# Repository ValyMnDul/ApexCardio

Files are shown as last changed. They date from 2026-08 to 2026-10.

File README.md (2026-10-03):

# ApexCardio

A portable cardiac and respiratory monitoring system built with an ESP32, ADS1292R and a Flutter mobile application.

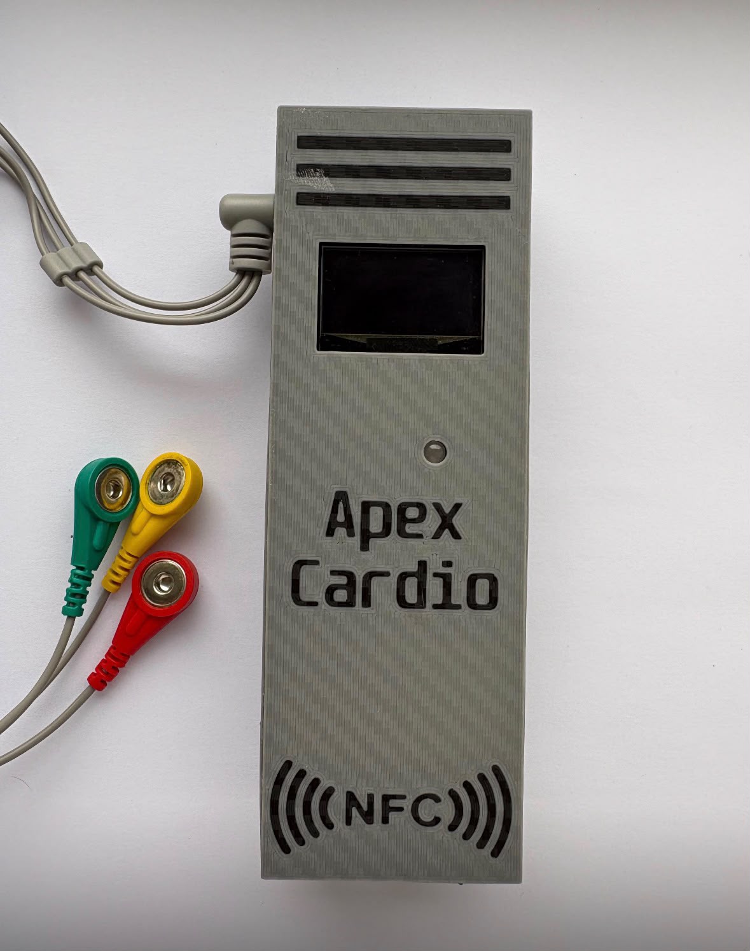
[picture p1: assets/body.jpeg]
Body


## Mobile App Screenshots

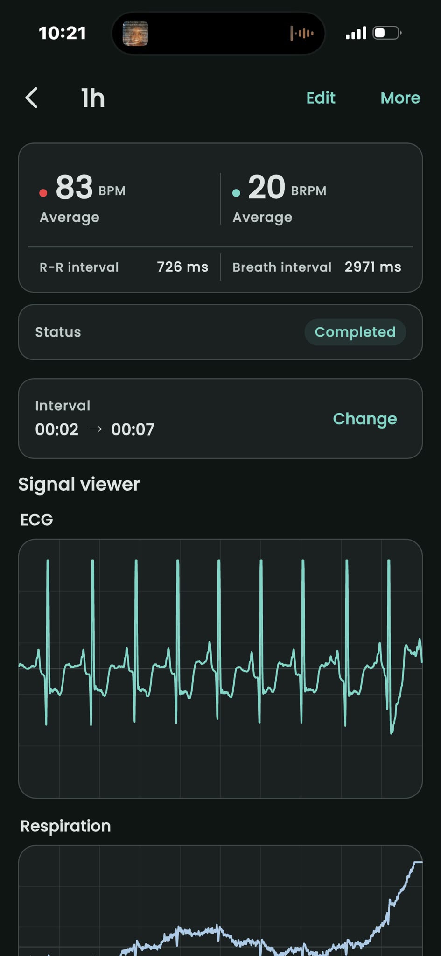
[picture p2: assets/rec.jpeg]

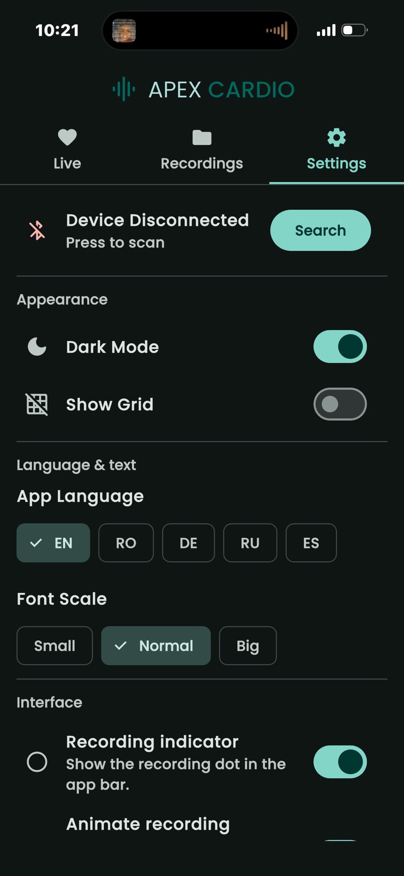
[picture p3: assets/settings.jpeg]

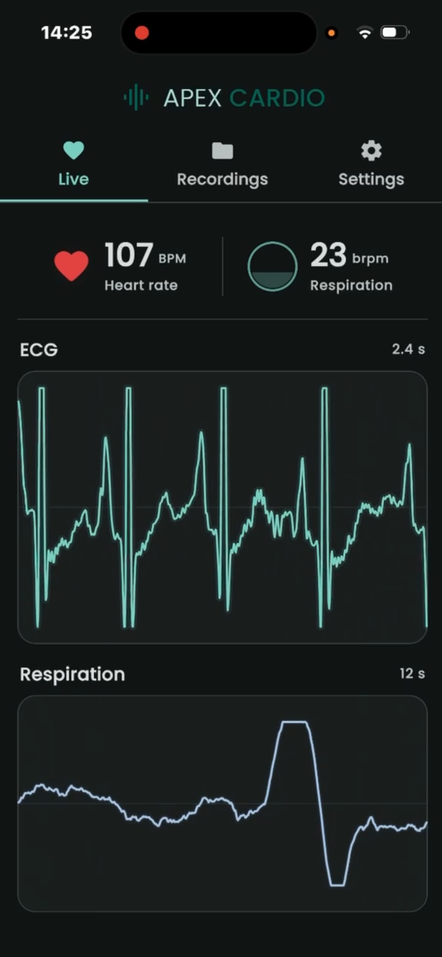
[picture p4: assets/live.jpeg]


## Features

- Real-time ECG monitoring
- Real-time respiratory monitoring
- Heart rate and respiratory rate
- Bluetooth Low Energy communication
- Live data visualization
- Recording and local storage with SQLite
- PDF and CSV export
- Automatic Bluetooth reconnection
- OLED display on the device

## Mobile App

The Flutter application is used to connect to the device, display ECG and respiratory data in real time, record measurements and manage saved recordings.

The app can work offline and stores recordings locally using SQLite.

## Hardware

The device uses:

- ESP32
- ADS1292R
- OLED display
- Rechargeable 18650 batteries
- ECG electrodes
- RGB status LED

The ADS1292R allows the device to acquire ECG and impedance-based respiratory signals using the same electrodes.

## Development

Most of my documented development time was spent working on the Flutter application, including the interface, Bluetooth communication, data buffering, live graphs, recording system, SQLite storage and export features.

I was not able to properly track the hardware development time because I did not have a good enough webcam to document the work, and recording the hardware work was difficult.

## Project Goal

The goal of ApexCardio is to create a compact and portable monitoring device that can acquire, process and display physiological signals without requiring a computer or external power source.

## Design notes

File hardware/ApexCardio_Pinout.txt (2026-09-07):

ApexCardio Hardware Pinout
Current ESP32 firmware pinout

ESP32 to ADS1292R / CJMCU-1292
GPIO18  -> SCK
GPIO19  -> MISO
GPIO23  -> MOSI
GPIO5   -> CS
GPIO22  -> DRDY
GPIO4   -> START
GPIO33  -> RESET / PWDN
5V/VIN  -> VDD / 5V
GND     -> GND

ADS1292R SPI settings
Clock: 100 kHz
Bit order: MSB first
SPI mode: MODE1

ESP32 to OLED SH1106 128x64
GPIO21  -> SDA
GPIO25  -> SCL
GND     -> GND
VCC     -> OLED supply

OLED interface: I2C
OLED bus clock used by firmware: 800 kHz

Current status LED
GPIO2   -> Status LED

Firmware behavior:
GPIO2 HIGH -> BLE connected
GPIO2 LOW  -> BLE disconnected

RGB LED extension
LED type: 5 mm RGB, common anode

Common anode -> ESP32 3.3V
Red cathode   -> 220-330 ohm resistor -> GPIO26
Green cathode -> 220-330 ohm resistor -> GPIO27
Blue cathode  -> 220-330 ohm resistor -> GPIO32

For a common-anode RGB LED:
GPIO LOW  -> color ON
GPIO HIGH -> color OFF

Note: GPIO26, GPIO27 and GPIO32 are free in the current main.cpp. The current firmware does not yet control the RGB LED on these pins.

Power system
Battery pack: 2 x 18650 Li-ion cells in parallel (1S2P)

Battery pack + -> TP4056 B+
Battery pack - -> TP4056 B-

TP4056 OUT+ -> MT3608 input +
TP4056 OUT- -> MT3608 input -

MT3608 output adjusted to 5.0 V

MT3608 output + -> ESP32 5V/VIN
MT3608 output - -> ESP32 GND

ESP32 5V/VIN -> CJMCU-1292 VDD / 5V
ESP32 GND -> CJMCU-1292 GND
ESP32 GND -> OLED GND

All system grounds must be common.

ECG electrode placement used during testing
Red electrode    -> below the right clavicle
Yellow electrode -> below the left clavicle
Third electrode  -> lower-right torso / RLD reference

The electrode cable connects to the CJMCU-1292 electrode input connector.

GPIO summary
GPIO2   -> Current status LED
GPIO4   -> ADS1292R START
GPIO5   -> ADS1292R CS
GPIO18  -> ADS1292R SCK
GPIO19  -> ADS1292R MISO
GPIO21  -> OLED SDA
GPIO22  -> ADS1292R DRDY
GPIO23  -> ADS1292R MOSI
GPIO25  -> OLED SCL
GPIO33  -> ADS1292R RESET / PWDN

Reserved for RGB extension:
GPIO26  -> RGB Red
GPIO27  -> RGB Green
GPIO32  -> RGB Blue

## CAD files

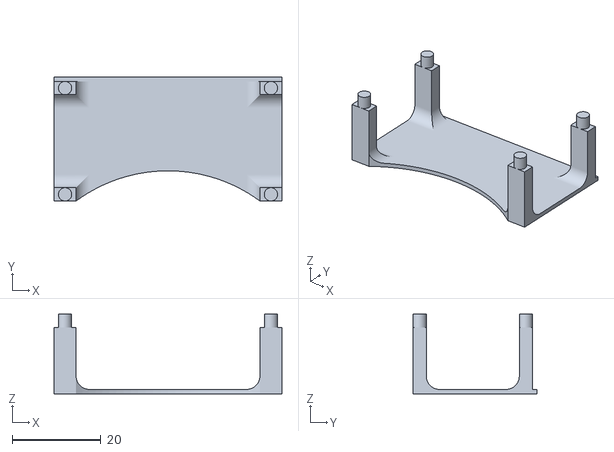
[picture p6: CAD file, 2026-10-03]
hardware/CAD/heartbot_screen_hold.stl
51.5 x 28.0 x 18.0

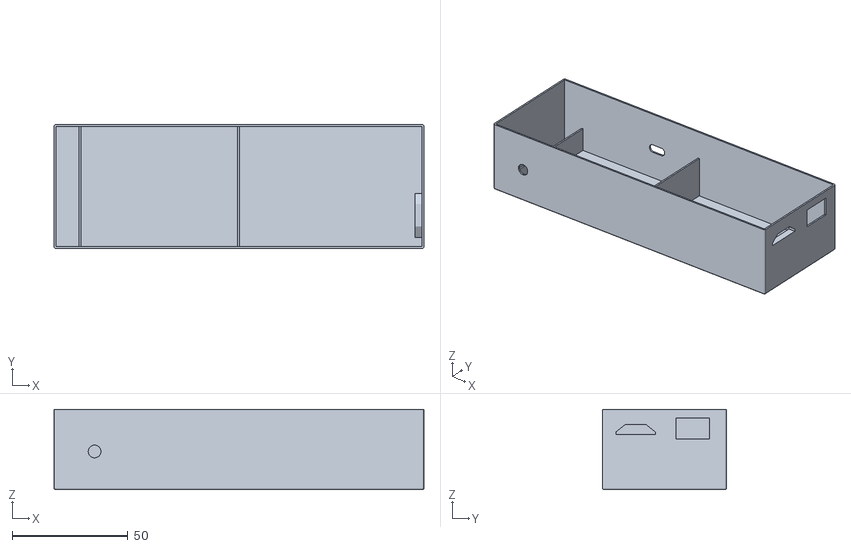
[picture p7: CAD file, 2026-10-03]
hardware/CAD/heartbot_body.stl
160.0 x 53.6 x 34.8

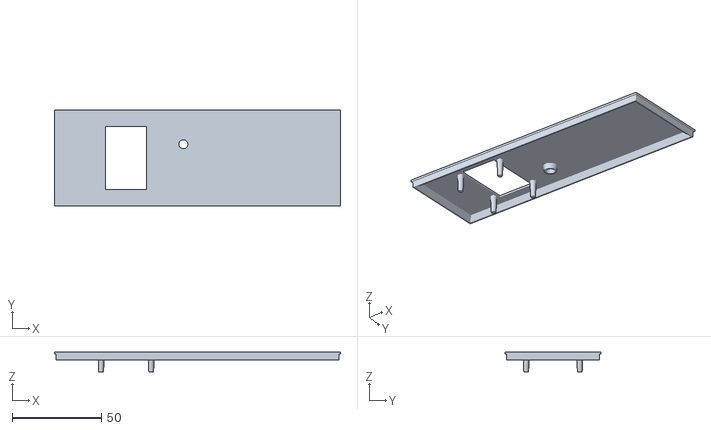
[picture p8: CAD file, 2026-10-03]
hardware/CAD/heartbot_cap.stl
160.0 x 53.6 x 11.0

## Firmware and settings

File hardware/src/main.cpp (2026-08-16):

#include <Arduino.h>
#include <SPI.h>
#include <Wire.h>
#include <U8g2lib.h>
#include <NimBLEDevice.h>
#include <math.h>

#define PIN_SCK 18
#define PIN_MISO 19
#define PIN_MOSI 23
#define PIN_CS 5
#define PIN_DRDY 22
#define PIN_START 4
#define PIN_RESET 33

#define OLED_SDA 21
#define OLED_SCL 25

#define CMD_START 0x08
#define CMD_RDATAC 0x10
#define CMD_SDATAC 0x11
#define CMD_RREG 0x20
#define CMD_WREG 0x40

#define DISP_W 128
#define DISP_H 64

#define FS 250
#define MWI_SIZE 38
#define SLOPE_SIZE 25
#define DETECTOR_CALIBRATION 500

#define LED_PIN 2

#define SAMPLES_PER_PACKET 10
#define BYTES_PER_SAMPLE 9
#define BLE_PACKET_SIZE (SAMPLES_PER_PACKET * BYTES_PER_SAMPLE)

#define SERVICE_UUID "12345678-1234-1234-1234-123456789abc"
#define CHARACTERISTIC_UUID "87654321-4321-4321-4321-cba987654321"

SPISettings adsSPI(
    100000,
    MSBFIRST,
    SPI_MODE1
);

U8G2_SH1106_128X64_NONAME_F_HW_I2C u8g2(
    U8G2_R0,
    U8X8_PIN_NONE
);

const int TOP_UI_H = 19;
const int PLOT_TOP = 21;
const int PLOT_BOTTOM = 63;
const int PLOT_CENTER = (PLOT_TOP + PLOT_BOTTOM) / 2;

const float DISPLAY_RANGE = 8050.0f;

const int PIXEL_DECIMATION = 3;
const unsigned long FRAME_INTERVAL = 36;

volatile bool adcRunning = false;

TaskHandle_t adcTaskHandle = nullptr;
QueueHandle_t ecgQueue = nullptr;

NimBLEServer* pServer = nullptr;
NimBLECharacteristic* pCaracteristic = nullptr;

bool deviceConnected = false;

uint8_t bleBuffer[BLE_PACKET_SIZE];
uint8_t bleSamplesCounter = 0;

uint8_t screenWave[DISP_W];

float pixelSamples[PIXEL_DECIMATION];
int pixelSampleCount = 0;

uint8_t pendingPixels[16];
int pendingCount = 0;

float morphSlow = 0.0f;

struct SensorSample
{
    float ecg;
    int32_t respiration;
};

volatile float bpmValue = 0.0f;
volatile uint32_t beatCount = 0;
volatile unsigned long heartFlashUntil = 0;

struct Biquad
{
    float b0;
    float b1;
    float b2;
    float a1;
    float a2;

    float x1;
    float x2;
    float y1;
    float y2;

    Biquad(
        float _b0,
        float _b1,
        float _b2,
        float _a1,
        float _a2
    )
    {
        b0 = _b0;
        b1 = _b1;
        b2 = _b2;
        a1 = _a1;
        a2 = _a2;

        x1 = 0.0f;
        x2 = 0.0f;
        y1 = 0.0f;
        y2 = 0.0f;
    }

    float process(float x)
    {
        float y =
            b0 * x +
            b1 * x1 +
            b2 * x2 -
            a1 * y1 -
            a2 * y2;

        x2 = x1;
        x1 = x;

        y2 = y1;
        y1 = y;

        return y;
    }
};

Biquad highPass(
    0.98763698f,
    -1.97527397f,
    0.98763698f,
    -1.97512112f,
    0.97542682f
);

Biquad notch50(
    0.98236277f,
    -0.60713358f,
    0.98236277f,
    -0.60713358f,
    0.96472554f
);

Biquad lowPass(
    0.17508764f,
    0.35017529f,
    0.17508764f,
    -0.51930341f,
    0.21965398f
);

Biquad qrsHighPass(
    0.91496914f,
    -1.82993829f,
    0.91496914f,
    -1.82269493f,
    0.83718165f
);

Biquad qrsLowPass(
    0.02785977f,
    0.05571953f,
    0.02785977f,
    -1.47548044f,
    0.58691951f
);

float q1 = 0;
float q2 = 0;
float q3 = 0;
float q4 = 0;

float mwiBuffer[MWI_SIZE];
int mwiIndex = 0;
float mwiSum = 0;

float slopeBuffer[SLOPE_SIZE];
int slopeIndex = 0;

float mwiPrev2 = 0;
float mwiPrev1 = 0;

float slopePrev2 = 0;
float slopePrev1 = 0;

uint32_t detectorSamples = 0;

bool detectorReady = false;

float calibrationMax = 0;
float calibrationSum = 0;
uint32_t calibrationPeaks = 0;

float signalLevel = 0;
float noiseLevel = 0;
float detectionThreshold = 0;

uint32_t lastQrsSample = 0;
float lastQrsSlope = 0;
float averageRR = 0;

uint16_t rrHistory[5];
int rrCount = 0;
int rrIndex = 0;

const int8_t startupECG[] = {
    0,0,0,0,0,
    1,2,3,4,4,3,2,1,0,
    0,-1,-2,-4,-2,0,
    3,8,17,21,8,
    -13,-9,-4,-1,0,
    0,1,2,3,4,6,8,9,10,
    10,10,9,8,7,6,5,4,3,2,1,
    0,0,0,0,0,0
};

const int startupCount =
    sizeof(startupECG) /
    sizeof(startupECG[0]);

class ServerCallbacks : public NimBLEServerCallbacks
{
    void onConnect(NimBLEServer* pServer) override
    {
        deviceConnected = true;
        digitalWrite(LED_PIN, HIGH);
    }

    void onDisconnect(NimBLEServer* pServer) override
    {
        deviceConnected = false;
        digitalWrite(LED_PIN, LOW);

        NimBLEDevice::getAdvertising()->start();
    }
};

void pack24(
    int32_t value,
    uint8_t* output
)
{
    if (value > 8388607)
        value = 8388607;

    if (value < -8388608)
        value = -8388608;

    uint32_t packed =
        ((uint32_t)value) &
        0xFFFFFF;

    output[0] =
        (packed >> 16) &
        0xFF;

    output[1] =
        (packed >> 8) &
        0xFF;

    output[2] =
        packed &
        0xFF;
}

void sendBLESample(
    float displayedECG,
    int32_t respirationRaw
)
{
    int offset =
        bleSamplesCounter *
        BYTES_PER_SAMPLE;

    bleBuffer[offset + 0] = 0xC0;
    bleBuffer[offset + 1] = 0x00;
    bleBuffer[offset + 2] = 0x00;

    pack24(
        (int32_t)displayedECG,
        &bleBuffer[offset + 3]
    );

    pack24(
        respirationRaw,
        &bleBuffer[offset + 6]
    );

    bleSamplesCounter++;

    if (
        bleSamplesCounter >=
        SAMPLES_PER_PACKET
    )
    {
        bleSamplesCounter = 0;

        if (
            deviceConnected &&
            pCaracteristic != nullptr
        )
        {
            pCaracteristic->setValue(
                bleBuffer,
                BLE_PACKET_SIZE
            );

            pCaracteristic->notify();
        }
    }
}

void initBLE()
{
    NimBLEDevice::init(
        "ApexCardio"
    );

    pServer =
        NimBLEDevice::createServer();

    pServer->setCallbacks(
        new ServerCallbacks()
    );

    NimBLEService* pService =
        pServer->createService(
            SERVICE_UUID
        );

    pCaracteristic =
        pService->createCharacteristic(
            CHARACTERISTIC_UUID,
            NIMBLE_PROPERTY::READ |
            NIMBLE_PROPERTY::NOTIFY
        );

    pService->start();

    NimBLEAdvertising* pAdvertising =
        NimBLEDevice::getAdvertising();

    pAdvertising->addServiceUUID(
        SERVICE_UUID
    );

    pAdvertising->start();
}

void adsCommand(uint8_t cmd)
{
    digitalWrite(PIN_CS, LOW);

    delayMicroseconds(10);

    SPI.transfer(cmd);

    delayMicroseconds(20);

    digitalWrite(PIN_CS, HIGH);

    delayMicroseconds(20);
}

void adsReset()
{
    digitalWrite(PIN_RESET, HIGH);
    delay(10);

    digitalWrite(PIN_RESET, LOW);
    delay(10);

    digitalWrite(PIN_RESET, HIGH);
    delay(200);
}

void writeRegister(
    uint8_t reg,
    uint8_t value
)
{
    digitalWrite(PIN_CS, LOW);

    delayMicroseconds(10);

    SPI.transfer(CMD_SDATAC);

    delayMicroseconds(100);

    SPI.transfer(
        CMD_WREG |
        reg
    );

    SPI.transfer(0x00);

    delayMicroseconds(100);

    SPI.transfer(value);

    delayMicroseconds(10);

    digitalWrite(PIN_CS, HIGH);

    delay(2);
}

uint8_t readRegister(
    uint8_t reg
)
{
    digitalWrite(PIN_CS, LOW);

    delayMicroseconds(10);

    SPI.transfer(CMD_SDATAC);

    delayMicroseconds(100);

    SPI.transfer(
        CMD_RREG |
        reg
    );

    SPI.transfer(0x00);

    delayMicroseconds(100);

    uint8_t value =
        SPI.transfer(0x00);

    delayMicroseconds(10);

    digitalWrite(PIN_CS, HIGH);

    return value;
}

int32_t make24(
    uint8_t a,
    uint8_t b,
    uint8_t c
)
{
    int32_t value =
        ((int32_t)a << 16) |
        ((int32_t)b << 8) |
        c;

    if (value & 0x800000)
    {
        value |= 0xFF000000;
    }

    return value;
}

float shapeForDisplay(
    float ecg
)
{
    morphSlow +=
        0.08f *
        (ecg - morphSlow);

    return
        ecg -
        0.08f *
        morphSlow;
}

uint8_t ecgToPixel(
    float value
)
{
    if (value > DISPLAY_RANGE)
        value = DISPLAY_RANGE;

    if (value < -DISPLAY_RANGE)
        value = -DISPLAY_RANGE;

    float normalized =
        value /
        DISPLAY_RANGE;

    int halfHeight =
        (PLOT_BOTTOM - PLOT_TOP) /
        2;

    int y =
        PLOT_CENTER -
        (int)(
            normalized *
            halfHeight
        );

    return constrain(
        y,
        PLOT_TOP,
        PLOT_BOTTOM
    );
}

void drawHeartOutline(
    int x,
    int y
)
{
    u8g2.drawCircle(
        x + 2,
        y + 2,
        2
    );

    u8g2.drawCircle(
        x + 6,
        y + 2,
        2
    );

    u8g2.drawLine(
        x,
        y + 3,
        x + 4,
        y + 9
    );

    u8g2.drawLine(
        x + 8,
        y + 3,
        x + 4,
        y + 9
    );
}

void drawHeartFilled(
    int x,
    int y
)
{
    u8g2.drawDisc(
        x + 2,
        y + 2,
        2
    );

    u8g2.drawDisc(
        x + 6,
        y + 2,
        2
    );

    u8g2.drawTriangle(
        x,
        y + 3,
        x + 8,
        y + 3,
        x + 4,
        y + 9
    );
}

void drawTopInfo()
{
    bool flash =
        millis() <
        heartFlashUntil;

    if (flash)
    {
        drawHeartFilled(
            2,
            1
        );
    }
    else
    {
        drawHeartOutline(
            2,
            1
        );
    }

    u8g2.setFont(
        u8g2_font_6x10_tf
    );

    u8g2.drawStr(
        15,
        8,
        "HR"
    );

    char bpmBuf[8];

    if (bpmValue >= 1.0f)
    {
        snprintf(
            bpmBuf,
            sizeof(bpmBuf),
            "%d",
            (int)(
                bpmValue +
                0.5f
            )
        );
    }
    else
    {
        snprintf(
            bpmBuf,
            sizeof(bpmBuf),
            "--"
        );
    }

    u8g2.setFont(
        u8g2_font_logisoso16_tn
    );

    u8g2.drawStr(
        33,
        16,
        bpmBuf
    );

    u8g2.setFont(
        u8g2_font_5x7_tf
    );

    char countBuf[14];

    snprintf(
        countBuf,
        sizeof(countBuf),
        "%lu",
        (unsigned long)
        beatCount
    );

    int width =
        u8g2.getStrWidth(
            countBuf
        );

    u8g2.drawStr(
        126 - width,
        7,
        countBuf
    );

    u8g2.drawHLine(
        0,
        TOP_UI_H,
        128
    );
}

void updateBPM(
    uint32_t rrSamples
)
{
    if (
        rrSamples < 75 ||
        rrSamples > 500
    )
    {
        return;
    }

    rrHistory[
        rrIndex
    ] =
        (uint16_t)
        rrSamples;

    rrIndex++;

    if (
        rrIndex >= 5
    )
    {
        rrIndex = 0;
    }

    if (
        rrCount < 5
    )
    {
        rrCount++;
    }

    uint16_t temp[5];

    for (
        int i = 0;
        i < rrCount;
        i++
    )
    {
        temp[i] =
            rrHistory[i];
    }

    for (
        int i = 0;
        i < rrCount - 1;
        i++
    )
    {
        for (
            int j = i + 1;
            j < rrCount;
            j++
        )
        {
            if (
                temp[j] <
                temp[i]
            )
            {
                uint16_t t =
                    temp[i];

                temp[i] =
                    temp[j];

                temp[j] =
                    t;
            }
        }
    }

    float rr;

    if (
        rrCount == 1
    )
    {
        rr =
            temp[0];
    }
    else if (
        rrCount % 2 ==
        1
    )
    {
        rr =
            temp[
                rrCount / 2
            ];
    }
    else
    {
        rr =
            (
                temp[
                    rrCount / 2 - 1
                ]
                +
                temp[
                    rrCount / 2
                ]
            )
            *
            0.5f;
    }

    bpmValue =
        15000.0f /
        rr;
}

void acceptBeat(
    uint32_t sample,
    float slope
)
{
    if (
        lastQrsSample != 0
    )
    {
        uint32_t rr =
            sample -
            lastQrsSample;

        updateBPM(
            rr
        );

        if (
            averageRR <=
            0.0f
        )
        {
            averageRR =
                rr;
        }
        else
        {
            averageRR =
                0.80f *
                averageRR +
                0.20f *
                rr;
        }
    }

    lastQrsSample =
        sample;

    lastQrsSlope =
        slope;

    beatCount++;

    heartFlashUntil =
        millis() +
        120;
}

float getMaxSlope()
{
    float maximum = 0;

    for (
        int i = 0;
        i < SLOPE_SIZE;
        i++
    )
    {
        if (
            slopeBuffer[i] >
            maximum
        )
        {
            maximum =
                slopeBuffer[i];
        }
    }

    return maximum;
}

void processQRSDetector(
    float ecg
)
{
    float qrs =
        qrsHighPass.process(
            ecg
        );

    qrs =
        qrsLowPass.process(
            qrs
        );

    float derivative =
        (
            2.0f * qrs +
            q1 -
            q3 -
            2.0f * q4
        )
        *
        0.125f;

    q4 = q3;
    q3 = q2;
    q2 = q1;
    q1 = qrs;

    float absSlope =
        fabsf(
            derivative
        );

    slopeBuffer[
        slopeIndex
    ] =
        absSlope;

    slopeIndex++;

    if (
        slopeIndex >=
        SLOPE_SIZE
    )
    {
        slopeIndex = 0;
    }

    float squared =
        derivative *
        derivative;

    mwiSum -=
        mwiBuffer[
            mwiIndex
        ];

    mwiBuffer[
        mwiIndex
    ] =
        squared;

    mwiSum +=
        squared;

    mwiIndex++;

    if (
        mwiIndex >=
        MWI_SIZE
    )
    {
        mwiIndex = 0;
    }

    float mwi =
        mwiSum /
        (float)
        MWI_SIZE;

    float slope =
        getMaxSlope();

    detectorSamples++;

    bool localPeak =
        mwiPrev1 >
        mwiPrev2 &&
        mwiPrev1 >=
        mwi;

    if (!detectorReady)
    {
        if (localPeak)
        {
            calibrationSum +=
                mwiPrev1;

            calibrationPeaks++;

            if (
                mwiPrev1 >
                calibrationMax
            )
            {
                calibrationMax =
                    mwiPrev1;
            }
        }

        if (
            detectorSamples >=
            DETECTOR_CALIBRATION
        )
        {
            float meanPeak =
                calibrationPeaks > 0
                ?
                calibrationSum /
                calibrationPeaks
                :
                calibrationMax *
                0.25f;

            noiseLevel =
                meanPeak *
                0.50f;

            signalLevel =
                calibrationMax *
                0.70f;

            if (
                signalLevel <=
                noiseLevel
            )
            {
                signalLevel =
                    noiseLevel *
                    2.0f +
                    1.0f;
            }

            detectionThreshold =
                noiseLevel +
                0.25f *
                (
                    signalLevel -
                    noiseLevel
                );

            detectorReady =
                true;
        }

        mwiPrev2 =
            mwiPrev1;

        mwiPrev1 =
            mwi;

        slopePrev2 =
            slopePrev1;

        slopePrev1 =
            slope;

        return;
    }

    if (localPeak)
    {
        float peak =
            mwiPrev1;

        float candidateSlope =
            slopePrev1;

        uint32_t candidateSample =
            detectorSamples -
            1;

        uint32_t distance =
            lastQrsSample == 0
            ?
            1000000
            :
            candidateSample -
            lastQrsSample;

        bool refractory =
            lastQrsSample != 0 &&
            distance < 60;

        bool possibleTWave =
            lastQrsSample != 0 &&
            distance < 90 &&
            lastQrsSlope > 0 &&
            candidateSlope <
            lastQrsSlope *
            0.50f;

        bool earlyLowSlope =
            lastQrsSample != 0 &&
            averageRR > 0 &&
            distance <
            averageRR *
            0.62f &&
            lastQrsSlope > 0 &&
            candidateSlope <
            lastQrsSlope *
            0.70f;

        detectionThreshold =
            noiseLevel +
            0.25f *
            (
                signalLevel -
                noiseLevel
            );

        if (
            peak >
            detectionThreshold &&
            !refractory &&
            !possibleTWave &&
            !earlyLowSlope
        )
        {
            signalLevel =
                0.875f *
                signalLevel +
                0.125f *
                peak;

            acceptBeat(
                candidateSample,
                candidateSlope
            );
        }
        else
        {
            float alpha =
                (
                    refractory ||
                    possibleTWave ||
                    earlyLowSlope
                )
                ?
                0.03f
                :
                0.125f;

            noiseLevel =
                (
                    1.0f -
                    alpha
                )
                *
                noiseLevel +
                alpha *
                peak;
        }
    }

    mwiPrev2 =
        mwiPrev1;

    mwiPrev1 =
        mwi;

    slopePrev2 =
        slopePrev1;

    slopePrev1 =
        slope;
}

void drawStartupWave(
    int endIndex
)
{
    const int x0 = 8;
    const int x1 = 120;
    const int baseline = 35;

    const float verticalScale =
        0.80f;

    float dx =
        (float)(
            x1 - x0
        )
        /
        (float)(
            startupCount - 1
        );

    int previousX =
        x0;

    int previousY =
        baseline -
        (int)(
            startupECG[0] *
            verticalScale
        );

    for (
        int i = 1;
        i <= endIndex &&
        i < startupCount;
        i++
    )
    {
        int x =
            x0 +
            (int)(
                dx *
                i
            );

        int y =
            baseline -
            (int)(
                startupECG[i] *
                verticalScale
            );

        u8g2.drawLine(
            previousX,
            previousY,
            x,
            y
        );

        previousX =
            x;

        previousY =
            y;
    }
}

void bootAnimation()
{
    const char* title =
        "ApexCardio";

    for (
        int frame = 0;
        frame < 24;
        frame++
    )
    {
        u8g2.clearBuffer();

        u8g2.setFont(
            u8g2_font_logisoso18_tf
        );

        int textWidth =
            u8g2.getStrWidth(
                title
            );

        u8g2.drawStr(
            (
                128 -
                textWidth
            )
            /
            2,
            17,
            title
        );

        int waveProgress =
            map(
                frame,
                0,
                23,
                1,
                startupCount - 1
            );

        drawStartupWave(
            waveProgress
        );

        u8g2.drawFrame(
            24,
            56,
            80,
            4
        );

        int progress =
            map(
                frame,
                0,
                23,
                0,
                78
            );

        if (
            progress > 0
        )
        {
            u8g2.drawBox(
                25,
                57,
                progress,
                2
            );
        }

        u8g2.sendBuffer();

        delay(85);
    }
}

void showMessage(
    const char* msg
)
{
    u8g2.clearBuffer();

    u8g2.setFont(
        u8g2_font_6x10_tf
    );

    int w =
        u8g2.getStrWidth(
            msg
        );

    u8g2.drawStr(
        (
            128 -
            w
        )
        /
        2,
        36,
        msg
    );

    u8g2.sendBuffer();
}

void IRAM_ATTR drdyISR()
{
    BaseType_t wake =
        pdFALSE;

    if (
        adcTaskHandle !=
        nullptr
    )
    {
        vTaskNotifyGiveFromISR(
            adcTaskHandle,
            &wake
        );

        if (wake)
        {
            portYIELD_FROM_ISR();
        }
    }
}
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
void loop()
{
    SensorSample sample;

    while (
        xQueueReceive(
            ecgQueue,
            &sample,
            0
        )
        ==
        pdTRUE
    )
    {
        createDisplayPixel(
            sample.ecg,
            sample.respiration
        );
    }

    static unsigned long lastFrame =
        0;

    if (
        millis() -
        lastFrame >=
        FRAME_INTERVAL
    )
    {
        lastFrame =
            millis();

        scrollWave();

        renderFrame();
    }

    delay(1);
}

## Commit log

2026-08-01 Add darkmode button
2026-08-03 Add PIO for esp32 coding environment
2026-08-03 Initialize ADS1292R and configure SPI settings
2026-08-04 Implement LED indication for BLE connection status
2026-08-06 Add ECG data processing and sample parsing in BleProvider
2026-08-09 make settings button works; enhance local storage fot showGrid variable
2026-08-13 Refactor main.cpp: reorganize code structure, add Biquad filter implementation, and improve ADS1292R initialization
2026-08-16 Fix ecg live signals
    [main.cpp]
2026-08-16 Add Respiration Samples
2026-08-19 Refactor BLE provider to use SensorSample class and add sample batch controller; implement respiration widget in Live tab
2026-08-19 fix: correct timerInterval syntax in ApexCardioLiveActivity and ApexCardioLockScreenView
2026-08-21 Refactor settings screen: Improve BLE scan dialog and settings layout
    - Updated BLE scan dialog to use Consumer2 for better state management.
    - Enhanced UI elements for device scanning, including improved button and list item designs.
    - Replaced _SettingLine with _SettingsSwitchRow for better readability and consistency.
    - Introduced _ChoiceSetting for language and font scale selection, improving user experience.
    - Adjusted padding and layout for a cleaner appearance across the settings screen.
2026-08-21 feat: update language strings and add device behavior settings
    - Updated language strings for start and end selection in multiple languages.
    - Added new language strings for device behavior, auto reconnect, and ApexCardio filtering.
    - Increased window duration and interval duration in recording viewer.
    - Modified interval picker to remove end time selection and adjust maximum interval logic.
    - Enhanced recording analysis service to handle timeline calculations more effectively.
    - Updated recording report service to change window duration for analysis.
    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
2026-08-21 feat: simplify BLE provider settings and enhance UI for connected device status
